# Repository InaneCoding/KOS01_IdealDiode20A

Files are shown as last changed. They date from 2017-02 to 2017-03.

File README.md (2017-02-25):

20A 5V-60V Ideal Diode PCB
Ideal Diode circuit based on the Linear Tech LT4359
By Kevin Bibby / http://www.inanecoding.co.uk
----------------------------------------------
v1.0 - 25/02/2017
First version for prototype.
Tested & functional on a basic level (not verified at full current level or behaviour of step response / protections etc).
To be refined for V2 based on things learnt after prototype.
Any comments let me know!

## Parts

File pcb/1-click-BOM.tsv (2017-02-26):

Qty | Reference | Description | Manufacturer | MPN | RS | Value
1 | U1 | Ideal Diode Controller MSOP-8 | Linear Tech | LTC4359IMS8 | 8516843 | LTC4359
1 | C1 | 1206 100V X7R 10% Capacitor | Murata | GRM31CR72A225KA73L | 8202863 | 2u2
1 | R1 | 0.5W 1206 Resistor | Panasonic | ERJP08F3601V | 7219866 | 3k6
1 | Q1 | N-Channel 60V 100A TDSON8 | Infineon | BSC028N06NS | 9064296 | BSC028N06NS
1 | D1 | 60V TVS 400W SMA | Taiwan Semi | SMAJ60A | 6873368 | SMAJ60A
1 | D2 | 24V TVS 400W SMA | Taiwan Semi | SMAJ24A | 7485161 | SMAJ24A
1 | Q2 | N-Channel 60V 100A TDSON8 | Infineon | BSC028N06NS | 9064296 | BSC028N06NS
1 | D3 | 16V 6% 0.2W Zener Diode SOD-323 | ON Semi | MM3Z16VT1G | 6878212 | MM3Z16VT1
1 | R3 | 0603 Resistor | TE | CRG0603F10R | 2132008 | 10R
1 | R2 | 0603 Resistor | TE | CRG0603F10K | 2132418 | 10k
1 | C2 | 0603 100V X7R 10% Capacitor | AVX | 06031C103K4Z2A | 6983210 | 10n
1 | R4 | 0603 Resistor | TE | CRG0603F1M0 | 2132676 | 1M
1 | P1 | 1x3way 2.54mm Header | Harwin | M20-9990345 | 6812975 | CONN_01X03

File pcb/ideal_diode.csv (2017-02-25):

Reference | Value | Footprint | Datasheet | ManufacturerName | ManufacturerPart | Description | Fit | rs
U1 | LTC4359 | Housings_SSOP:MSOP-8_3x3mm_Pitch0.65mm |  | Linear Tech | LTC4359IMS8 | Ideal Diode Controller MSOP-8 | True | 8516843
C1 | 2u2 | Capacitors_SMD:C_1206 |  | Murata | GRM31CR72A225KA73L | 1206 100V X7R 10% Capacitor | True | 8202863
R1 | 3k6 | Resistors_SMD:R_1206 |  | Panasonic | ERJP08F3601V | 0.5W 1206 Resistor | True | 7219866
Q1 | BSC028N06NS | _kb_footprint:TDSON-8-1 |  | Infineon | BSC028N06NS | N-Channel 60V 100A TDSON8 | True | 9064296
D1 | SMAJ60A | Diodes_SMD:SMA_Standard |  | Taiwan Semi | SMAJ60A | 60V TVS 400W SMA | True | 6873368
D2 | SMAJ24A | Diodes_SMD:SMA_Standard |  | Taiwan Semi | SMAJ24A | 24V TVS 400W SMA | True | 7485161
Q2 | BSC028N06NS | _kb_footprint:TDSON-8-1 |  | Infineon | BSC028N06NS | N-Channel 60V 100A TDSON8 | True | 9064296
D3 | MM3Z16VT1 | Diodes_SMD:SOD-323 |  | ON Semi | MM3Z16VT1G | 16V 6% 0.2W Zener Diode SOD-323 | True | 6878212
R3 | 10R | Resistors_SMD:R_0603 |  | TE | CRG0603F10R | 0603 Resistor | True | 2132008
R2 | 10k | Resistors_SMD:R_0603 |  | TE | CRG0603F10K | 0603 Resistor | True | 2132418
C2 | 10n | Capacitors_SMD:C_0603 |  | AVX | 06031C103K4Z2A | 0603 100V X7R 10% Capacitor | True | 6983210
R4 | 1M | Resistors_SMD:R_0603 |  | TE | CRG0603F1M0 | 0603 Resistor | True | 2132676
OUT1 | CONN_01X01 | Wire_Pads:SolderWirePad_single_2-5mmDrill |  | _ | _ | Hole for solder / screw | False | _
GND2 | CONN_01X01 | Wire_Pads:SolderWirePad_single_2-5mmDrill |  | _ | _ | Hole for solder / screw | False | _
IN1 | CONN_01X01 | Wire_Pads:SolderWirePad_single_2-5mmDrill |  | _ | _ | Hole for solder / screw | False | _
GND1 | CONN_01X01 | Wire_Pads:SolderWirePad_single_2-5mmDrill |  | _ | _ | Hole for solder / screw | False | _
P1 | CONN_01X03 | Pin_Headers:Pin_Header_Straight_1x03 |  | Harwin | M20-9990345 | 1x3way 2.54mm Header | True | 6812975

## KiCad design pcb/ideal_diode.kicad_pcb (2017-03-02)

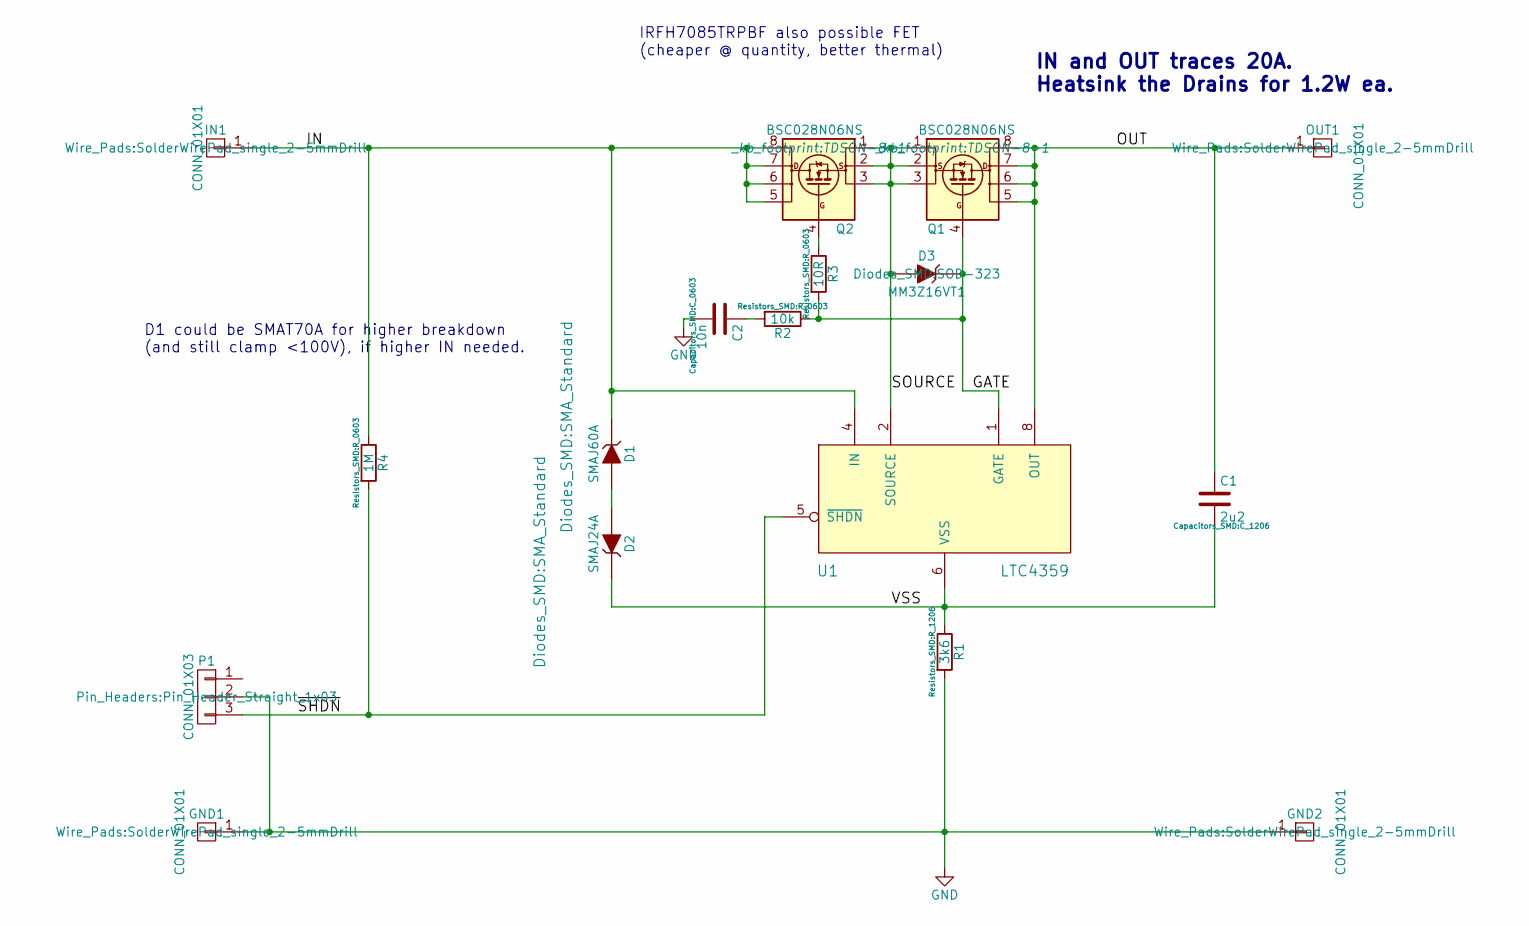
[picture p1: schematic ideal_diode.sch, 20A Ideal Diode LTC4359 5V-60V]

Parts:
C1: 2u2; C_1206; ManufacturerPart GRM31CR72A225KA73L
C2: 10n; C_0603; ManufacturerPart 06031C103K4Z2A
D1: SMAJ60A; SMA_Standard; ManufacturerPart SMAJ60A
D2: SMAJ24A; SMA_Standard; ManufacturerPart SMAJ24A
D3: MM3Z16VT1; SOD-323; ManufacturerPart MM3Z16VT1G
GND1, GND2: CONN_01X01; SolderWirePad_single_2-5mmDrill; ManufacturerPart _
IN1: CONN_01X01; SolderWirePad_single_2-5mmDrill; ManufacturerPart _
OUT1: CONN_01X01; SolderWirePad_single_2-5mmDrill; ManufacturerPart _
P1: CONN_01X03; Pin_Header_Straight_1x03; ManufacturerPart M20-9990345
Q1, Q2: BSC028N06NS; TDSON-8-1; ManufacturerPart BSC028N06NS
R1: 3k6; R_1206; ManufacturerPart ERJP08F3601V
R2: 10k; R_0603; ManufacturerPart CRG0603F10K
R3: 10R; R_0603; ManufacturerPart CRG0603F10R
R4: 1M; R_0603; ManufacturerPart CRG0603F1M0
U1: LTC4359; MSOP-8_3x3mm_Pitch0.65mm; ManufacturerPart LTC4359IMS8

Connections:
/GATE: D3.1 (K), Q1.4 (G), R2.1, R3.2, U1.1 (GATE)
/IN: D1.1 (K), IN1.1, Q2.5 (D), Q2.6 (D), Q2.7 (D), Q2.8 (D), R4.1, U1.4 (IN)
/OUT: C1.1, OUT1.1, Q1.5 (D), Q1.6 (D), Q1.7 (D), Q1.8 (D), U1.8 (OUT)
/SOURCE: D3.2 (A), Q1.1 (S), Q1.2 (S), Q1.3 (S), Q2.1 (S), Q2.2 (S), Q2.3 (S), U1.2 (SOURCE)
/VSS: C1.2, D2.1 (K), R1.1, U1.6 (VSS)
/~SHDN: P1.3, R4.2, U1.5 (~SHDN)
GND: C2.2, GND1.1, GND2.1, P1.2, R1.2
unnamed: C2.1, R2.2
unnamed: D1.2 (A), D2.2 (A)
unnamed: Q2.4 (G), R3.1

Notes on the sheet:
IN and OUT traces 20A. Heatsink the Drains for 1.2W ea.
IRFH7085TRPBF also possible FET (cheaper @ quantity, better thermal)
D1 could be SMAT70A for higher breakdown (and still clamp <100V), if higher IN needed.

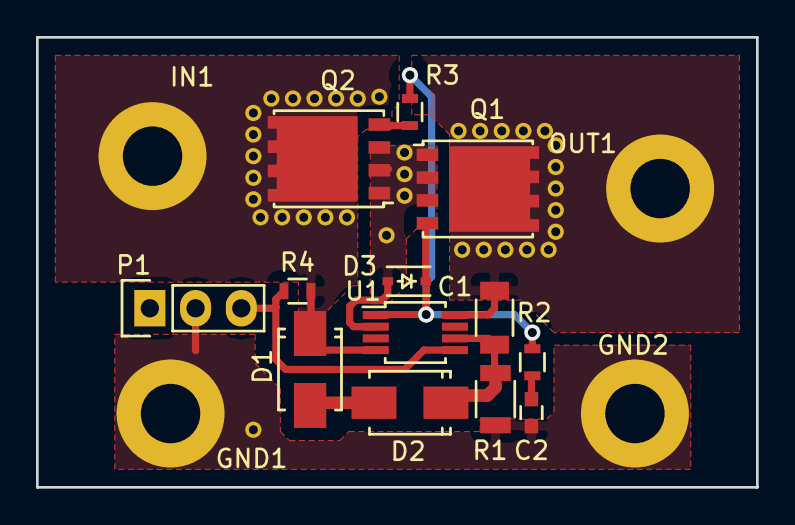
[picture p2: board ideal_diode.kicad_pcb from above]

Board: 2 copper layers, 40.0 x 25.0 mm, 17 parts (0 on the bottom side), 10 nets.

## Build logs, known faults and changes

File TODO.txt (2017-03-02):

FOR V2.0
Test! (20A continuous, step response, reverse & overvoltage protection, input/output shorts)
move P1 away from GND1 hole
silkscreen on /SHDN header P1 describing
make for M4 bolts (incl bigger pads), leave enough clearance for ring crimp terminals
move bottom half compoents slightly to left to give even space
make whole PCB taller - square? to give better thermal, lower resistance etc
silkscreen to show big diode for main function - bottom? also for big +ve and -ve signs

be very careful when soldering, must have damaged LTC4359 before! Solder Q1 Q2 first.
LTC4359I only 85C (125C for H version), cut plane back slightly & move FETS upwards to stop heating up? Consider H version.
possibly use larger R1 value, but smaller case size. Sacrifices some of the minimum voltage to reduce power in component during reverse protection fault
option to BOM fit change to BSC016N06NSATMA1 fets for 1.5mohm instead of 2.5mohm Rdson
Change from 60V protection to 70V to allow higher input voltage?
remove second ground hole and just have single? removes dissipation in  GND tracks & two ring terminals could be attached on one hole
Fix Q1 Q2 D3 missing 3D models

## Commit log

2016-02-03 initial commit of v1.0 prototype kicad design files & generated gerbers & drill files simulation file for ltspice BOM info incomplete
    [ideal_diode-B.Cu.gbl, ideal_diode-B.Mask.gbs, ideal_diode-Edge.Cuts.gm1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]
2016-02-03 added title, date & version numbers to kicad schematic & pcb added *.kicad_pcb-bak *.bak *.net to git ignore
    [ideal_diode.kicad_pcb, ideal_diode.sch]
2016-03-05 adding tab-separated version of BOM
    [ideal_diode.tsv]
2016-03-05 renamed BOM to correct filename for kitnic.it added yaml description for for kitnic
    [1-Click-BOM.tsv]
2016-03-05 made 1-click-BOM lower-case 'C' to match yaml removed ending full stop from tsv line in yaml file
    [1-click-BOM.tsv]
2016-03-05 testing with kitnic... ...copied drill files from drill/ directory to gerbers directory (expected there) ...re-exported board outline with layer alignment target deleted - may be causing issues with 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
    [1-click-BOM.tsv, ideal_diode.csv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]
2016-03-05 removed layer alignment target from other layers (only did on outline previously) saved in kicad design
    [ideal_diode.kicad_pcb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]
2016-12-10 changing to v0.9 ready for tag of version at prototype stage
    [ideal_diode.kicad_pcb, ideal_diode.sch]
2016-12-10 setting license as CERN OHL updating titleblocks ready for 1.0 release, added silkscreen ID & version. changed from 4V-70V to 5V-60V to reflect design capabilities changed R1 from 1k to 3k6 & removed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
    [ideal_diode.kicad_pcb, ideal_diode.sch]
2017-02-25 last few changes for v1.0 Release Added part info for commodity R's and P1 Re-exported BOM and PCB data after minor changes since proto v0.9 added MPNs to one click BOM Updated readme & TODO, dates &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
    [1-click-BOM.tsv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]
2017-02-26 added quantity column needed by kitnic / 1-click-bom
    [1-click-BOM.tsv]
2017-03-02 moved FETs upwards & centred IN/OUT holes to FETs made PCB slightly wider added thermal relief on pads connecting to planes removed extra text from thermal via components so pcb design not cluttered
    [ideal_diode.kicad_pcb]
